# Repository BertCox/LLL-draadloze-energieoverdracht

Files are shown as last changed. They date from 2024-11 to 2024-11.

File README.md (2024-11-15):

# LLL-draadloze-energieoverdracht
PCB ontwerpen van de transmitter en receiver voor Levenslang Leren binnen de KU Leuven, campus Rabot.

De zender bestaat uit één enkele PCB, de ontvanger uit 4 aparte PCB's die met elkaar dienen te worden verbonden.
Een overzicht van de nodige componenten per PCB kan terug gevonden worden in de BOM-files (Bill of Material)

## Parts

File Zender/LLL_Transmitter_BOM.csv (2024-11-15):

Id | Designator | Footprint | Quantity | Designation | Supplier and ref
1 | C12 | C_Disc_D8.0mm_W2.5mm_P5.00mm | 1 | 390n
2 | J1 | BarrelJack_Horizontal | 1 | DCJ0303
3 | D1 | D_SMA | 1 | 1N4004
4 | C2,C1 | CP_Radial_D10.0mm_P5.00mm | 2 | 1200u
5 | R8,R4,R9,R6,R7 | R_0805_2012Metric_Pad1.20x1.40mm_HandSolder | 5 | 100k
6 | IC1 | TO-220-11_P3.4x5.08mm_StaggerOdd_Lead4.85mm_Vertical | 1 | LM18201
7 | C11,C10 | C_0805_2012Metric_Pad1.18x1.45mm_HandSolder | 2 | 10n
8 | TP1,TP3,TP2 | TestPoint_Loop_D1.80mm_Drill1.0mm_Beaded | 3 | TestPoint_Small
9 | RV1 | Potentiometer_Piher_PT-10-V05_Vertical | 1 | 1k
10 | F1 | Fuse_Bourns_MF-SM_7.98x5.44mm | 1 | Fuse
11 | TP_GND | TestPoint_Loop_D2.50mm_Drill1.0mm | 1 | TestPoint_Small
12 | J2 | PinHeader_1x02_P2.54mm_Vertical | 1 | CurrentSense
13 | C9,C4,C5,C8,C7 | C_0805_2012Metric_Pad1.18x1.45mm_HandSolder | 5 | 100n
14 | R5 | R_0805_2012Metric_Pad1.20x1.40mm_HandSolder | 1 | 2k
15 | R2 | R_0805_2012Metric_Pad1.20x1.40mm_HandSolder | 1 | 68k
16 | J3 | TerminalBlock_Phoenix_MKDS-1,5-2_1x02_P5.00mm_Horizontal | 1 | Screw_Terminal_01x02
17 | U2 | SOT-23-6_Handsoldering | 1 | LTC6990CS6TRPBF
18 | C6,C3 | CP_Radial_D5.0mm_P2.00mm | 2 | 100u
19 | U1 | SOT-223-3_TabPin2 | 1 | LM2936-5.0
20 | R3 | R_0805_2012Metric_Pad1.20x1.40mm_HandSolder | 1 | 910k
21 | R1 | R_0805_2012Metric_Pad1.20x1.40mm_HandSolder | 1 | 0

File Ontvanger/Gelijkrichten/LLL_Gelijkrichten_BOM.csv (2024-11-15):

Id | Designator | Footprint | Quantity | Designation | Supplier and ref
1 | D4,D1,D2,D3 | D_SMA | 4 | MRA4007T3G
2 | TP1,TP2,TP3 | TestPoint_Loop_D1.80mm_Drill1.0mm_Beaded | 3 | TestPoint_Small
3 | J3 | PinHeader_1x02_P2.54mm_Vertical | 1 | CurrentSense
4 | J1 | Connector_Female_LLL | 1 | Conn_01x06_Socket
5 | D5 | LED_0805_2012Metric_Pad1.15x1.40mm_HandSolder | 1 | LED
6 | C1 | CP_Elec_6.3x5.9 | 1 | C_Polarized_Small
7 | J2 | Connector_Male_LLL | 1 | Conn_01x06_Pin
8 | TP_GND | TestPoint_Loop_D2.50mm_Drill1.0mm | 1 | TestPoint_Small
9 | R3,R2,R1,R4 | R_0805_2012Metric_Pad1.20x1.40mm_HandSolder | 4 | RESISTOR0603
10 | COMP1 | SOT95P280X125-5N | 1 | BA8391G-TR
11 | C2 | C_0805_2012Metric_Pad1.18x1.45mm_HandSolder | 1 | 10u
12 | U1 | SOT91P240X110-3N | 1 | ZXTR2105FQ
13 | R5 | R_0805_2012Metric_Pad1.20x1.40mm_HandSolder | 1 | 470
14 | MOSFET1 | SOIC127P600X175-8N | 1 | N-MOSFET-SO8S

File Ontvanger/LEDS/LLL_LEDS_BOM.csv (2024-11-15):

Id | Designator | Footprint | Quantity | Designation | Supplier and ref
1 | D1,D2,D3 | LED_0805_2012Metric_Pad1.15x1.40mm_HandSolder | 3 | LED
2 | R3,R2,R1 | R_0805_2012Metric_Pad1.20x1.40mm_HandSolder | 3 | R
3 | TP1 | TestPoint_Loop_D1.80mm_Drill1.0mm_Beaded | 1 | TestPoint_Small
4 | J1 | PinHeader_1x02_P2.54mm_Vertical | 1 | CurrentSense
5 | TP_GND1 | TestPoint_Loop_D2.50mm_Drill1.0mm | 1 | TestPoint_Small
6 | J2 | Connector_Male_LLL | 1 | Conn_01x06_Pin

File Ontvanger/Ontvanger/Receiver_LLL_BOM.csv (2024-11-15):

Id | Designator | Footprint | Quantity | Designation | Supplier and ref
1 | J2 | TerminalBlock_RND_205-00001_1x02_P5.00mm_Horizontal | 1 | Screw_Terminal_01x02
2 | J1 | Connector_Female_LLL | 1 | Conn_01x06_Socket
3 | J3,J4 | conn_2x04_LLL | 2 | Conn_02x04_Counter_Clockwise

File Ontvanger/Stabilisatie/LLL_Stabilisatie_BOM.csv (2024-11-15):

Id | Designator | Footprint | Quantity | Designation | Supplier and ref
1 | R3 | R_0805_2012Metric_Pad1.20x1.40mm_HandSolder | 1 | 220k
2 | TP4 | TestPoint_Loop_D1.80mm_Drill1.0mm_Beaded | 1 | TestPoint_Small
3 | D1 | LED_0805_2012Metric_Pad1.15x1.40mm_HandSolder | 1 | LED
4 | J1 | Connector_Female_LLL | 1 | Conn_01x06_Socket
5 | L1 | L_6.3x6.3_H3 | 1 | 10uH
6 | R4 | R_0805_2012Metric_Pad1.20x1.40mm_HandSolder | 1 | 47k
7 | C4,C5 | C_0805_2012Metric_Pad1.18x1.45mm_HandSolder | 2 | 22u
8 | C1,C2 | C_0805_2012Metric_Pad1.18x1.45mm_HandSolder | 2 | 100n
9 | U1 | SOT-23-6 | 1 | TPS54308
10 | R1,R5 | R_0805_2012Metric_Pad1.20x1.40mm_HandSolder | 2 | 56k
11 | R2 | R_0805_2012Metric_Pad1.20x1.40mm_HandSolder | 1 | 7.5k
12 | J2 | Connector_Male_LLL | 1 | Conn_01x06_Pin
13 | C3 | C_0805_2012Metric_Pad1.18x1.45mm_HandSolder | 1 | 10u
14 | TP_GND | TestPoint_Loop_D2.50mm_Drill1.0mm | 1 | TestPoint_Small

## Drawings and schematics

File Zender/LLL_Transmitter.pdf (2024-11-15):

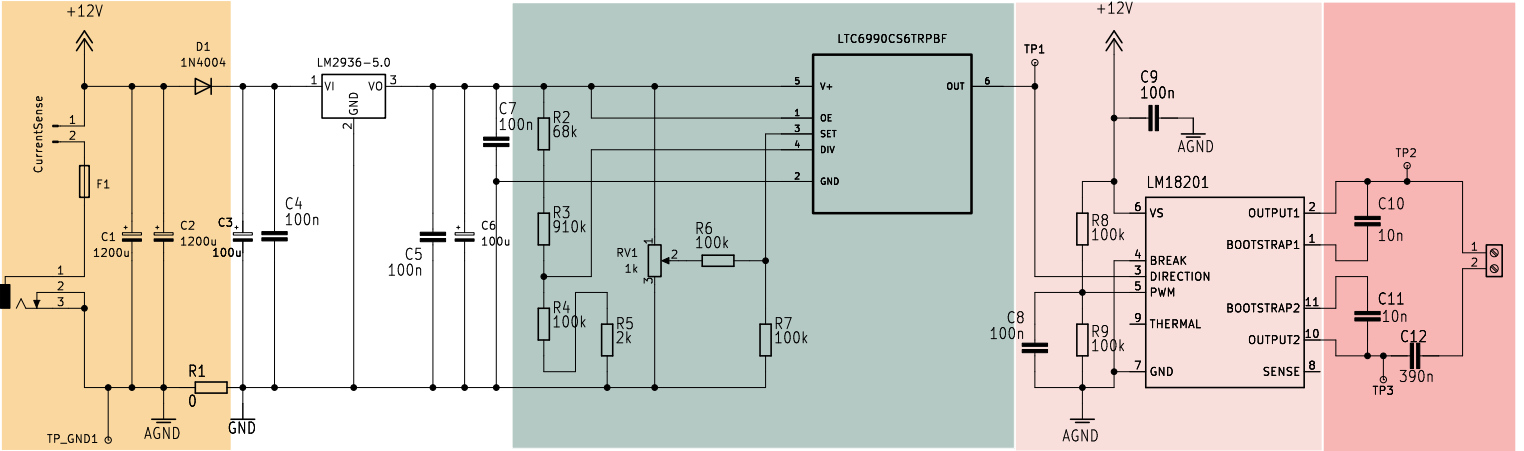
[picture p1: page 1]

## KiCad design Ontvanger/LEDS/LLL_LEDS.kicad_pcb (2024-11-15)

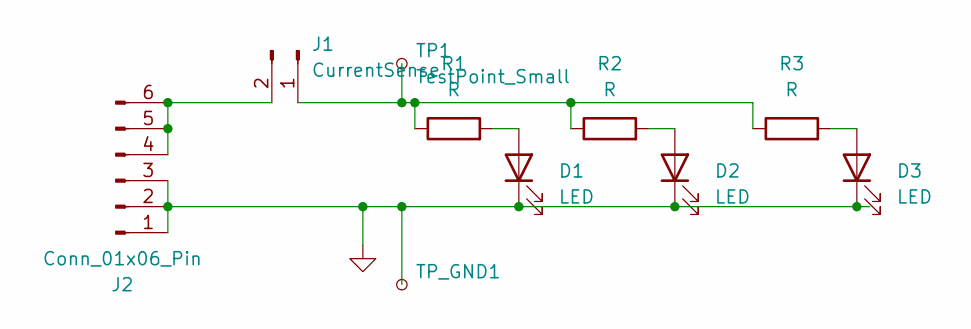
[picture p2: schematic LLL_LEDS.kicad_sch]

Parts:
D1, D2, D3: LED; LED_0805_2012Metric_Pad1.15x1.40mm_HandSolder
J1: CurrentSense; PinHeader_1x02_P2.54mm_Vertical
J2: Conn_01x06_Pin; Connector_Male_LLL
R1, R2, R3: R; R_0805_2012Metric_Pad1.20x1.40mm_HandSolder
TP1: TestPoint_Small; TestPoint_Loop_D1.80mm_Drill1.0mm_Beaded
TP_GND1: TestPoint_Small; TestPoint_Loop_D2.50mm_Drill1.0mm

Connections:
GND: D1.1 (K), D2.1 (K), D3.1 (K), J2.1, J2.2, J2.3, TP_GND1.1
unnamed: D1.2 (A), R1.2
unnamed: D2.2 (A), R2.2
unnamed: D3.2 (A), R3.2
unnamed: J1.1, R1.1, R2.1, R3.1, TP1.1
unnamed: J1.2, J2.4, J2.5, J2.6

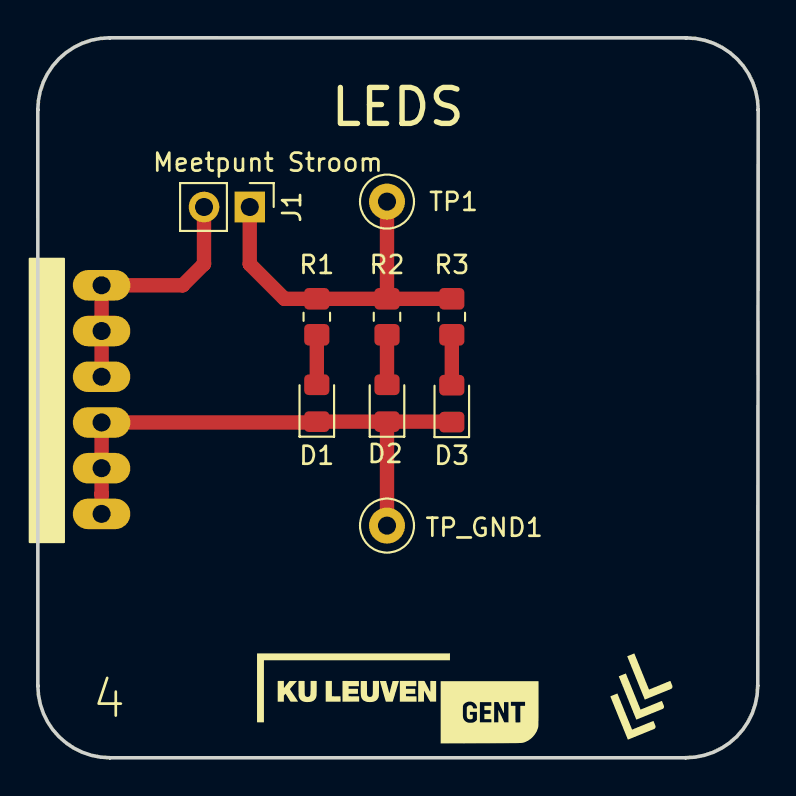
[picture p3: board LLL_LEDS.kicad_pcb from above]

Board: 2 copper layers, 40.0 x 40.0 mm, 10 parts (0 on the bottom side), 6 nets.

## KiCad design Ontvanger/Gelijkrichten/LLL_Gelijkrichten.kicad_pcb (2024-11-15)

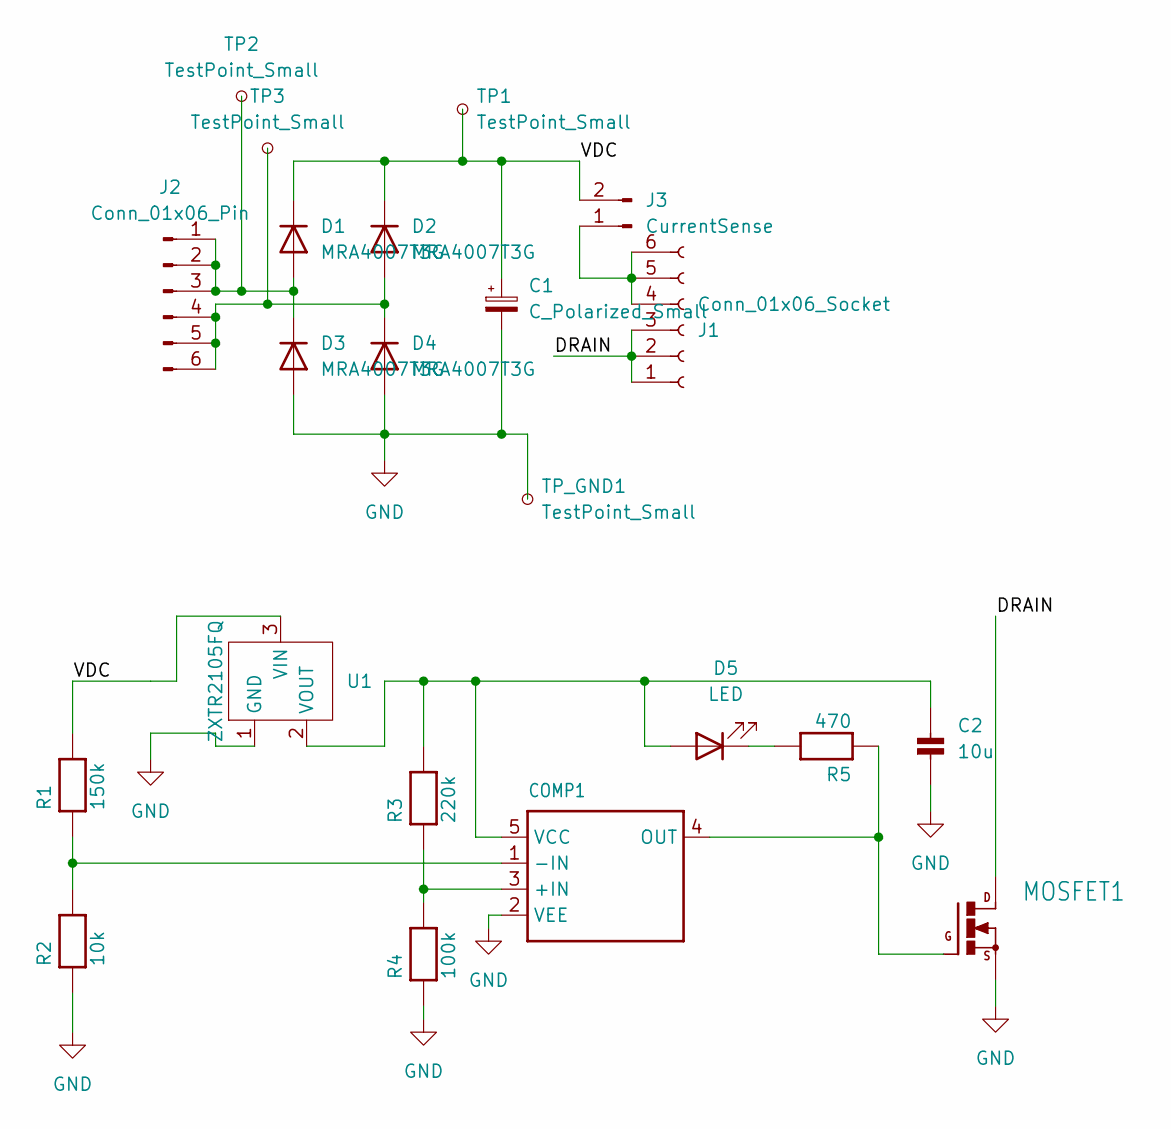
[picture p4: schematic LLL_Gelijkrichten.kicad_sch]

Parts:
C1: C_Polarized_Small; CP_Elec_6.3x5.9
C2: 10u; C_0805_2012Metric_Pad1.18x1.45mm_HandSolder
COMP1: BA8391G-TR; SOT95P280X125-5N
D1, D2, D3, D4: MRA4007T3G; D_SMA
D5: LED; LED_0805_2012Metric_Pad1.15x1.40mm_HandSolder
J1: Conn_01x06_Socket; Connector_Female_LLL
J2: Conn_01x06_Pin; Connector_Male_LLL
J3: CurrentSense; PinHeader_1x02_P2.54mm_Vertical
MOSFET1: N-MOSFET-SO8S; SOIC127P600X175-8N
R1: 150k; R_0805_2012Metric_Pad1.20x1.40mm_HandSolder
R2: 10k; R_0805_2012Metric_Pad1.20x1.40mm_HandSolder
R3: 220k; R_0805_2012Metric_Pad1.20x1.40mm_HandSolder
R4: 100k; R_0805_2012Metric_Pad1.20x1.40mm_HandSolder
R5: 470; R_0805_2012Metric_Pad1.20x1.40mm_HandSolder
TP1, TP2, TP3: TestPoint_Small; TestPoint_Loop_D1.80mm_Drill1.0mm_Beaded
TP_GND1: TestPoint_Small; TestPoint_Loop_D2.50mm_Drill1.0mm
U1: ZXTR2105FQ; SOT91P240X110-3N

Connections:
/DRAIN: J1.1, J1.2, J1.3, MOSFET1.5 (D), MOSFET1.6 (D), MOSFET1.7 (D), MOSFET1.8 (D)
/VDC: C1.1, D1.1 (K), D2.1 (K), J3.2, R1.2, TP1.1, U1.3 (VIN)
GND: C1.2, C2.2, COMP1.2 (VEE), D3.2 (A), D4.2 (A), MOSFET1.1 (S), MOSFET1.2 (S), MOSFET1.3 (S), R2.1, R4.1, U1.1 (GND); also elsewhere on the board
unnamed: C2.1, COMP1.5 (VCC), D5.2 (A), R3.2, U1.2 (VOUT)
unnamed: COMP1.3 (+IN), R3.1, R4.2
unnamed: COMP1.1 (-IN), R1.1, R2.2
unnamed: COMP1.4 (OUT), MOSFET1.4 (G), R5.1
unnamed: D1.2 (A), D3.1 (K), J2.1, J2.2, J2.3, TP2.1
unnamed: D2.2 (A), D4.1 (K), J2.4, J2.5, J2.6, TP3.1
unnamed: D5.1 (K), R5.2
unnamed: J1.4, J1.5, J1.6, J3.1

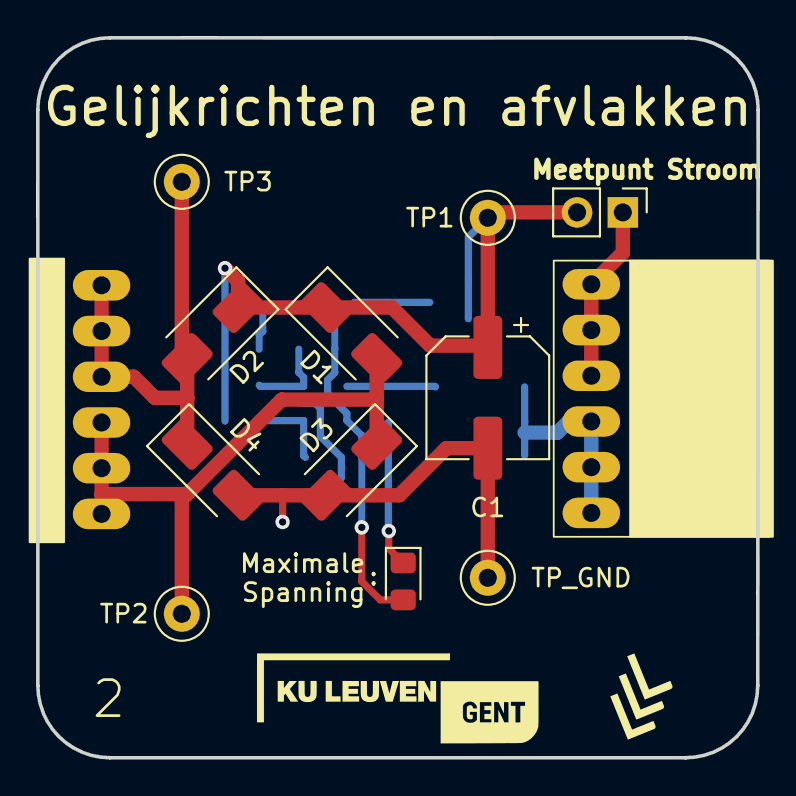
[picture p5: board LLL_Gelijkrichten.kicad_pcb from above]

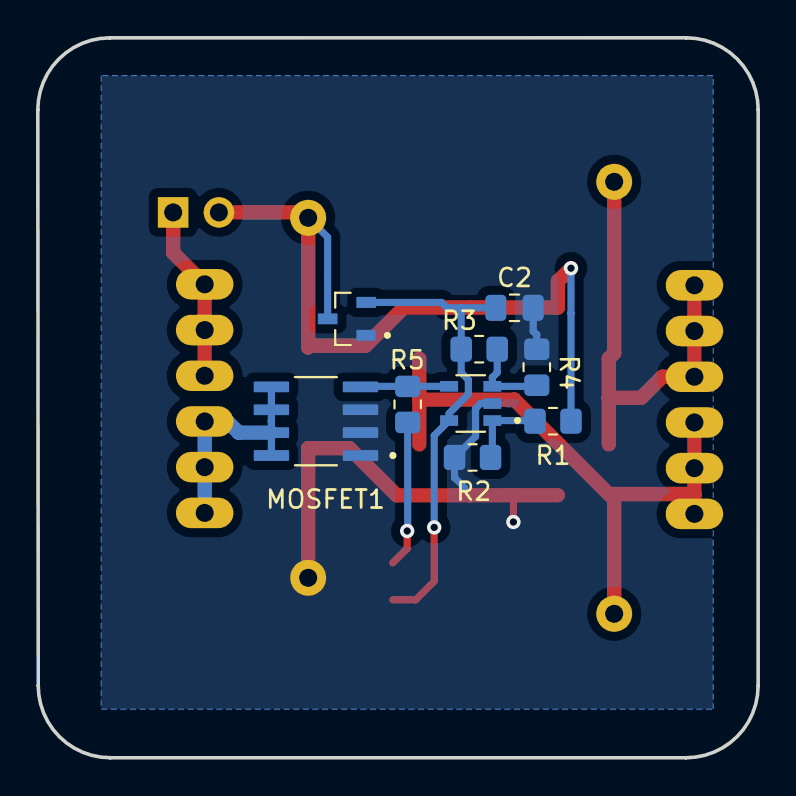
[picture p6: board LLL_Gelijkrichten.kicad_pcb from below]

Board: 2 copper layers, 40.0 x 40.0 mm, 22 parts (9 on the bottom side), 11 nets.

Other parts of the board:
TP_GND: TestPoint_Small; TestPoint_Loop_D2.50mm_Drill1.0mm

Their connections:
GND: TP_GND.1; also elsewhere on the board

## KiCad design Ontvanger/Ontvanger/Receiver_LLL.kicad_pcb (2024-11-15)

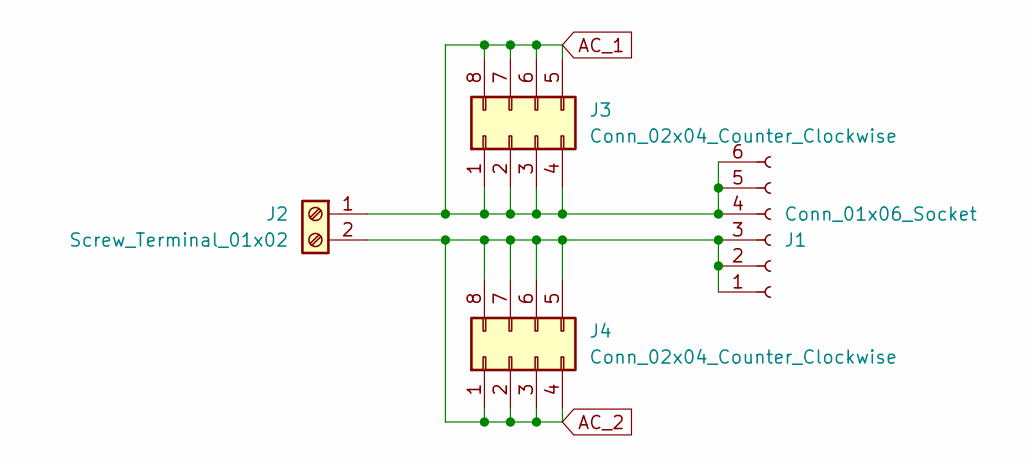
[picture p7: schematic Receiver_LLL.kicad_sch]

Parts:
J1: Conn_01x06_Socket; Connector_Female_LLL
J2: Screw_Terminal_01x02; TerminalBlock_RND_205-00001_1x02_P5.00mm_Horizontal
J3, J4: Conn_02x04_Counter_Clockwise; conn_2x04_LLL

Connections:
AC_1: J1.4, J1.5, J1.6, J2.1, J3.1, J3.2, J3.3, J3.4, J3.5, J3.6, J3.7, J3.8
AC_2: J1.1, J1.2, J1.3, J2.2, J4.1, J4.2, J4.3, J4.4, J4.5, J4.6, J4.7, J4.8

Board: 2 copper layers, 4 parts (0 on the bottom side), 2 nets, no tracks yet.

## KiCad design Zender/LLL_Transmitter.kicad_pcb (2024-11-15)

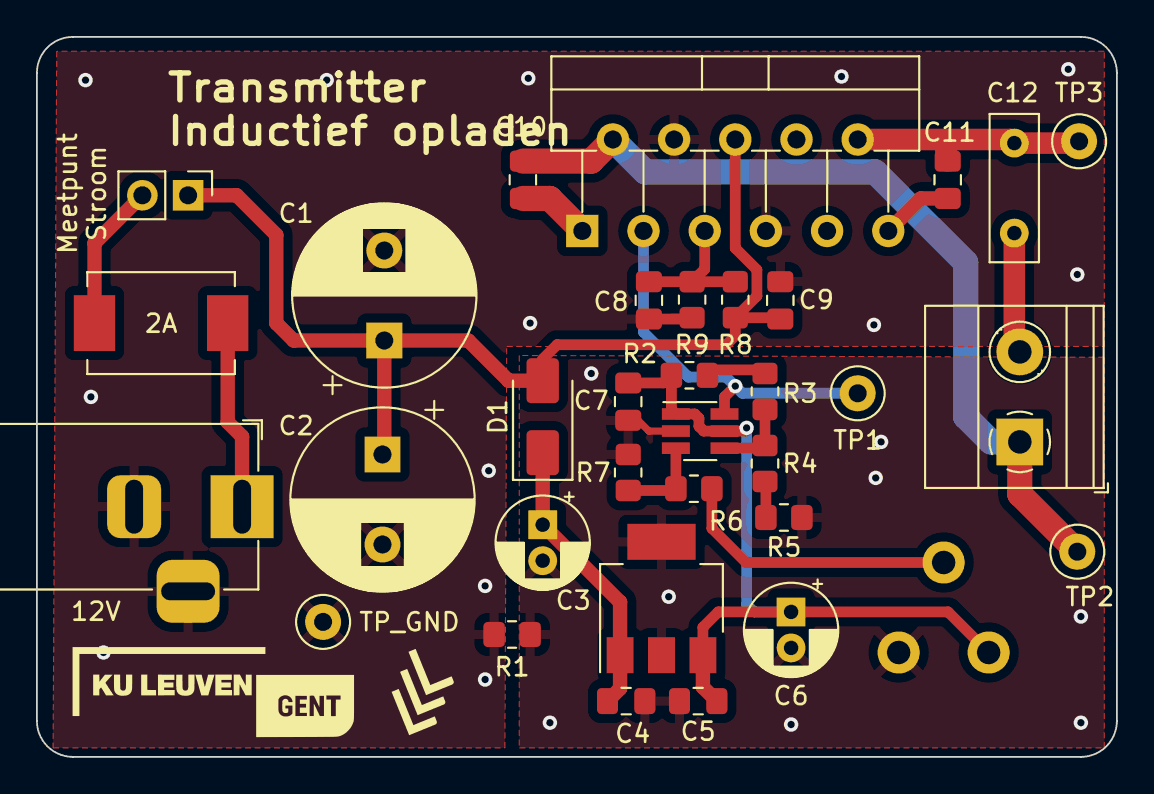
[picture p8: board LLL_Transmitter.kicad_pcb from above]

Board: 2 copper layers, 60.0 x 40.0 mm, 34 parts (0 on the bottom side), 19 nets.

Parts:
C1, C2: 1200u; CP_Radial_D10.0mm_P5.00mm
C3, C6: 100u; CP_Radial_D5.0mm_P2.00mm
C4, C5, C7, C8, C9: 100n; C_0805_2012Metric_Pad1.18x1.45mm_HandSolder
C10, C11: 10n; C_0805_2012Metric_Pad1.18x1.45mm_HandSolder
C12: 390n; C_Disc_D8.0mm_W2.5mm_P5.00mm
D1: 1N4004; D_SMA
F1: Fuse; Fuse_Bourns_MF-SM_7.98x5.44mm
IC1: LM18201; TO-220-11_P3.4x5.08mm_StaggerOdd_Lead4.85mm_Vertical
J1: DCJ0303; BarrelJack_Horizontal
J2: CurrentSense; PinHeader_1x02_P2.54mm_Vertical
J3: Screw_Terminal_01x02; TerminalBlock_Phoenix_MKDS-1,5-2_1x02_P5.00mm_Horizontal
R1: 0; R_0805_2012Metric_Pad1.20x1.40mm_HandSolder
R2: 68k; R_0805_2012Metric_Pad1.20x1.40mm_HandSolder
R3: 910k; R_0805_2012Metric_Pad1.20x1.40mm_HandSolder
R4, R6, R7, R8, R9: 100k; R_0805_2012Metric_Pad1.20x1.40mm_HandSolder
R5: 2k; R_0805_2012Metric_Pad1.20x1.40mm_HandSolder
RV1: 1k; Potentiometer_Piher_PT-10-V05_Vertical
TP1, TP2, TP3: TestPoint_Small; TestPoint_Loop_D1.80mm_Drill1.0mm_Beaded
TP_GND: TestPoint_Small; TestPoint_Loop_D2.50mm_Drill1.0mm
U1: LM2936-5.0; SOT-223-3_TabPin2
U2: LTC6990CS6TRPBF; SOT-23-6_Handsoldering

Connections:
+12V: C1.1, C2.1, C9.1, D1.2 (A), IC1.6 (VS), J2.1, R8.2
AGND: C1.2, C2.2, C8.2, C9.2, IC1.4 (BREAK), IC1.7 (GND), J1.2, J1.3, R1.1, R9.1, TP_GND.1
GND: C3.2, C4.2, C5.2, C6.2, C7.2, R1.2, R5.1, R7.1, RV1.3, U1.2 (GND), U2.2 (GND)
unnamed: C3.1, C4.1, D1.1 (K), U1.1 (VI)
unnamed: F1.2, J1.1
unnamed: C10.2, IC1.1 (BOOTSTRAP1)
unnamed: C11.1, IC1.11 (BOOTSTRAP2)
unnamed: IC1.3 (DIRECTION), TP1.1, U2.6 (OUT)
unnamed: C10.1, IC1.2 (OUTPUT1), J3.1, TP2.1
unnamed: C11.2, C12.1, IC1.10 (OUTPUT2), TP3.1
unnamed: C8.1, IC1.5 (PWM), R8.1, R9.2
unnamed: F1.1, J2.2
unnamed: C12.2, J3.2
unnamed: R2.1, R3.2
unnamed: R4.1, R5.2
unnamed: R6.2, RV1.2
unnamed: C5.1, C6.1, C7.1, R2.2, RV1.1, U1.3 (VO), U2.1 (OE), U2.5 (V+)
unnamed: R3.1, R4.2, U2.4 (DIV)
unnamed: R6.1, R7.2, U2.3 (SET)

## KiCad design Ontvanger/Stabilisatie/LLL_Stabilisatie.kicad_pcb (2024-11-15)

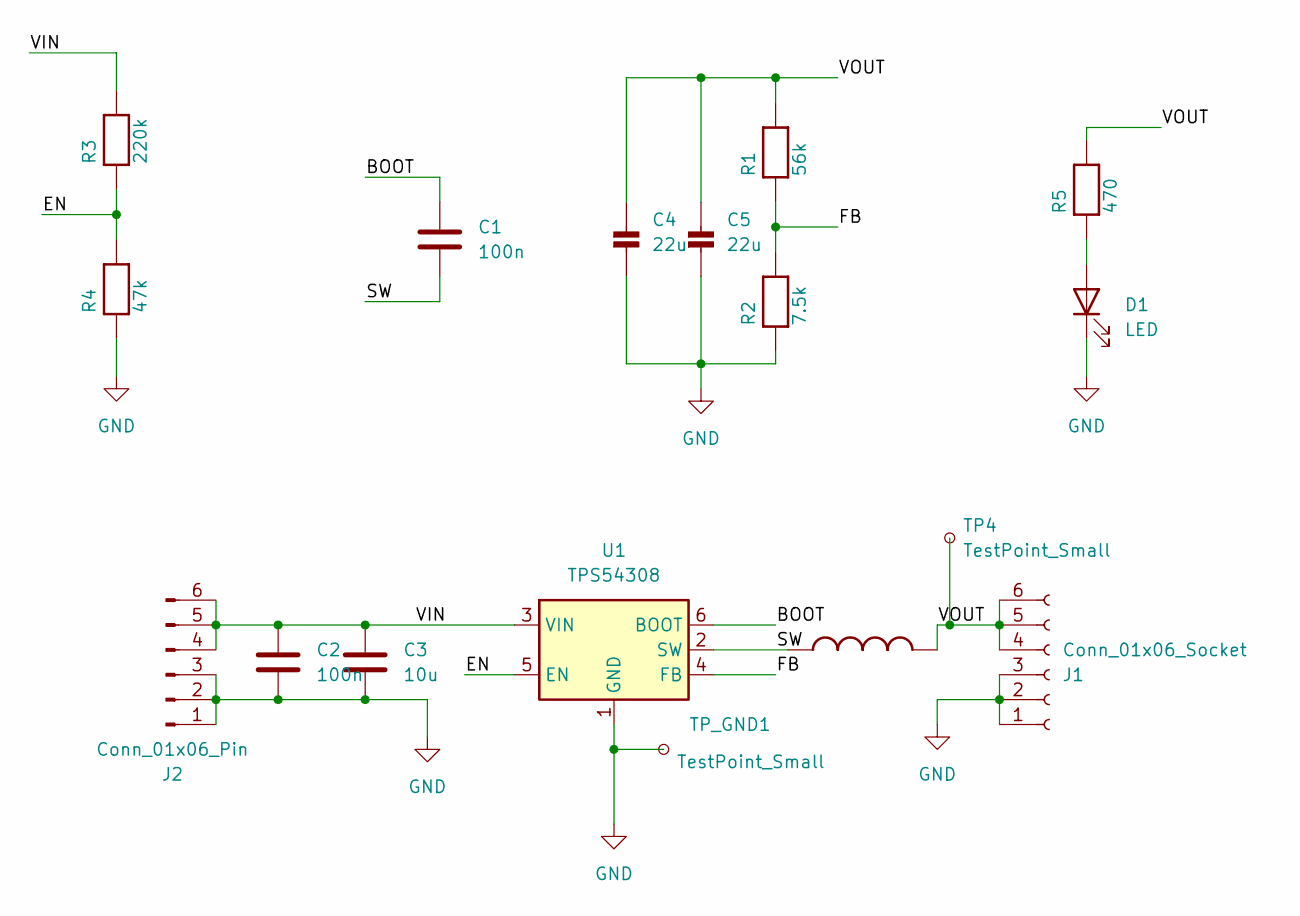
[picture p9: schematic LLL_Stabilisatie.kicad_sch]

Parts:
C1, C2: 100n; C_0805_2012Metric_Pad1.18x1.45mm_HandSolder
C3: 10u; C_0805_2012Metric_Pad1.18x1.45mm_HandSolder
C4, C5: 22u; C_0805_2012Metric_Pad1.18x1.45mm_HandSolder
D1: LED; LED_0805_2012Metric_Pad1.15x1.40mm_HandSolder
J1: Conn_01x06_Socket; Connector_Female_LLL
J2: Conn_01x06_Pin; Connector_Male_LLL
L1: 10uH; L_6.3x6.3_H3
R1: 56k; R_0805_2012Metric_Pad1.20x1.40mm_HandSolder
R2: 7.5k; R_0805_2012Metric_Pad1.20x1.40mm_HandSolder
R3: 220k; R_0805_2012Metric_Pad1.20x1.40mm_HandSolder
R4: 47k; R_0805_2012Metric_Pad1.20x1.40mm_HandSolder
R5: 470; R_0805_2012Metric_Pad1.20x1.40mm_HandSolder
TP4: TestPoint_Small; TestPoint_Loop_D1.80mm_Drill1.0mm_Beaded
TP_GND1: TestPoint_Small; TestPoint_Loop_D2.50mm_Drill1.0mm
U1: TPS54308; SOT-23-6

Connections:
/BOOT: C1.1, U1.6 (BOOT)
/EN: R3.1, R4.2, U1.5 (EN)
/FB: R1.1, R2.2, U1.4 (FB)
/SW: C1.2, L1.1, U1.2 (SW)
/VIN: C2.1, C3.1, J2.4, J2.5, J2.6, R3.2, U1.3 (VIN)
/VOUT: C4.1, C5.1, J1.4, J1.5, J1.6, L1.2, R1.2, R5.2, TP4.1
GND: C2.2, C3.2, C4.2, C5.2, D1.1 (K), J1.1, J1.2, J1.3, J2.1, J2.2, J2.3, R2.1, R4.1, TP_GND1.1, U1.1 (GND); also elsewhere on the board
unnamed: D1.2 (A), R5.1

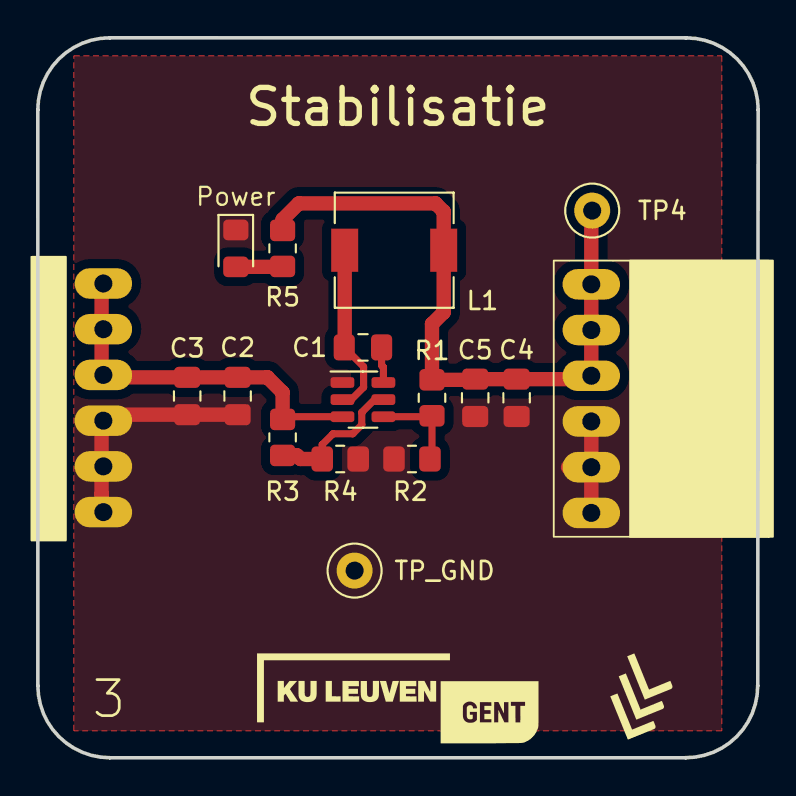
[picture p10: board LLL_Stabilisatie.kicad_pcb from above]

Board: 2 copper layers, 40.0 x 40.0 mm, 17 parts (0 on the bottom side), 8 nets.

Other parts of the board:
TP_GND: TestPoint_Small; TestPoint_Loop_D2.50mm_Drill1.0mm

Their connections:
GND: TP_GND.1; also elsewhere on the board
